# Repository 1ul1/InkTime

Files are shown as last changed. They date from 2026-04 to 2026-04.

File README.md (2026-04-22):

# InkTime
## Block Diagram

If GitHub does not render Mermaid, use this ASCII version instead:

# Block Diagram

### Summary

The nRF52840 is the main controller of the board.
Power comes from USB-C and the Li-Po battery through the BQ25180 charger and the RT6160A DC/DC regulator. The MCU talks over I2C with the BMA421 IMU, MAX17048 fuel gauge, and DRV2605 haptic driver. It also controls the E-Paper display through SPI and extra control lines, reads the buttons, and exposes SWD for programming and debug.

### Overview
```
USB-C -----> nRF52840 <-----> BMA421 IMU
  |             |               (I2C)
  |             |
  |             +-------------> Buttons
  |             |
  |             +-------------> SWD Header
  |             |
  |             +-------------> E-Paper Display
  |                    (SPI + control)
  |
  +-----> BQ25180 Charger -----> Li-Po Battery
                 |
                 +-----> RT6160A DC/DC -----> 3V3 
                                          |-> nRF52840
                                          |-> MAX17048 Fuel Gauge
                                          |-> DRV2605 Haptic Driver
                                          |-> E-Paper Drive Circuit
```

## Bill of Materials (BOM)

The table below lists the main parts used in the project.  
For standard passives (0201 / 0402 capacitors and resistors), the exact values and designators are already included in `BOM.csv`.  
JLC links below are **search links**, so you can quickly find the matching part on JLC Parts.

| Designators | Qty | Part / Function | Manufacturer | MPN | Package / Notes | JLC Parts | Datasheet |
|---|---:|---|---|---|---|---|---|
| U1 | 1 | Main MCU | Nordic Semiconductor | nRF52840 | AQFN-73 / 7x7 mm | [JLC Search](https://jlcpcb.com/parts/componentSearch?searchTxt=nRF52840) | [Datasheet](https://docs.nordicsemi.com/bundle/ps_nrf52840/page/keyfeatures_html5.html) |
| IC1 | 1 | Li-Po charger | Texas Instruments | BQ25180YBGR | DSBGA-8 | [JLC Search](https://jlcpcb.com/parts/componentSearch?searchTxt=BQ25180YBGR) | [Datasheet](https://www.ti.com/lit/gpn/BQ25180) |
| IC9 | 1 | Buck-boost regulator | Richtek | RT6160AWSC | WL-CSP-15 | [JLC Search](https://jlcpcb.com/parts/componentSearch?searchTxt=RT6160AWSC) | [Datasheet](https://www.mouser.com/datasheet/2/1458/DS6160A_02-3104604.pdf) |
| IC3 | 1 | IMU / accelerometer | Bosch Sensortec | BMA423 | LGA-12 | [JLC Search](https://jlcpcb.com/parts/componentSearch?searchTxt=BMA423) | [Datasheet](https://watchy.sqfmi.com/assets/files/BST-BMA423-DS000-1509600-950150f51058597a6234dd3eaafbb1f0.pdf) |
| U3 | 1 | Fuel gauge | Analog Devices / Maxim | MAX17048G+T10 | 9-bump UCSP | [JLC Search](https://jlcpcb.com/parts/componentSearch?searchTxt=MAX17048G%2BT10) | [Datasheet](https://www.analog.com/media/en/technical-documentation/data-sheets/max17048-max17049.pdf) |
| IC2 | 1 | Haptic driver | Texas Instruments | DRV2605YZFR | DSBGA-9 | [JLC Search](https://jlcpcb.com/parts/componentSearch?searchTxt=DRV2605YZFR) | [Datasheet](https://www.ti.com/lit/ds/symlink/drv2605.pdf) |
| ANT1 | 1 | 2.4 GHz chip antenna | Johanson Technology | 2450AT18B100E | Ceramic antenna | [JLC Search](https://jlcpcb.com/parts/componentSearch?searchTxt=2450AT18B100E) | [Datasheet](https://www.johansontechnology.com/docs/1187/2450AT18B100_X8XXogU.pdf) |
| J1 | 1 | E-paper FPC connector | Molex | 503480-2400 | 24-pin, 0.5 mm pitch | [JLC Search](https://jlcpcb.com/parts/componentSearch?searchTxt=503480-2400) | [Datasheet](https://www.molex.com/en-us/products/part-detail/5034802400) |
| J4 | 1 | USB-C connector | Kinghelm | KH-TYPE-C-16P | USB Type-C, SMT | [JLC Search](https://jlcpcb.com/parts/componentSearch?searchTxt=KH-TYPE-C-16P) | [Datasheet](https://datasheet.lcsc.com/lcsc/2404191039_Shenzhen-Kinghelm-Elec-KH-TYPE-C-16P_C709357.pdf) |
| J2 | 1 | SWD programming connector | Tag-Connect | TC2030-IDC | 6-pin cable / debug | [JLC Search](https://jlcpcb.com/parts/componentSearch?searchTxt=TC2030-IDC) | [Datasheet](https://www.tag-connect.com/wp-content/uploads/bsk-pdf-manager/2019/12/TC2030-IDC-Datasheet-Rev-B.pdf) |
| D3 | 1 | USB ESD protection | STMicroelectronics | USBLC6-2SC6Y | SOT-23-6 | [JLC Search](https://jlcpcb.com/parts/componentSearch?searchTxt=USBLC6-2SC6Y) | [Datasheet](https://www.st.com/resource/en/datasheet/usblc6-2sc6y.pdf) |
| D2, D4, D5 | 3 | Schottky diode | onsemi | MBR0530 | SOD-123 | [JLC Search](https://jlcpcb.com/parts/componentSearch?searchTxt=MBR0530) | [Datasheet](https://www.onsemi.com/pdf/datasheet/mbr0530t1-d.pdf) |
| Q3 | 1 | N-MOSFET | Vishay | SI1308EDL-T1-GE3 | SC-70 | [JLC Search](https://jlcpcb.com/parts/componentSearch?searchTxt=SI1308EDL-T1-GE3) | [Datasheet](https://www.vishay.com/docs/63399/si1308edl.pdf) |
| Q1 | 1 | P-MOSFET | Diodes Inc. / equivalent | DMG2305UX-7 | SOT-23 | [JLC Search](https://jlcpcb.com/parts/componentSearch?searchTxt=DMG2305UX-7) | [Datasheet](https://www.diodes.com/assets/Datasheets/DMG2305UX.pdf) |
| L7 | 1 | Power inductor | TDK | MLP2016SR47MT0S1 | 0.47 uH | [JLC Search](https://jlcpcb.com/parts/componentSearch?searchTxt=MLP2016SR47MT0S1) | [Datasheet](https://product.tdk.com/system/files/dam/doc/product/inductor/inductor/smd/catalog/inductor_commercial_multilayer_mlp2016_en.pdf) |
| L5 | 1 | Inductor | Generic / selected by value | 68uH | E-paper drive | [JLC Search](https://jlcpcb.com/parts/componentSearch?searchTxt=68uH) | - |
| L2 | 1 | Inductor | Generic / selected by value | 10uH | Power stage | [JLC Search](https://jlcpcb.com/parts/componentSearch?searchTxt=10uH) | - |
| L1 | 1 | RF inductor | Generic / selected by value | 3.9nH | RF matching | [JLC Search](https://jlcpcb.com/parts/componentSearch?searchTxt=3.9nH) | - |
| L3 | 1 | RF inductor | Generic / selected by value | 15nH | RF matching | [JLC Search](https://jlcpcb.com/parts/componentSearch?searchTxt=15nH) | - |
| X1 | 1 | High-frequency crystal | Generic / selected by value | 32MHz | 2016 package | [JLC Search](https://jlcpcb.com/parts/componentSearch?searchTxt=32MHz) | - |
| X2 | 1 | RTC crystal | Generic / selected by value | 32.768kHz | 3215 package | [JLC Search](https://jlcpcb.com/parts/componentSearch?searchTxt=32.768kHz) | - |
| SW_UP, SW_ENT, SW_DN | 3 | Push buttons | Panasonic | EVP-AKE31A | SMD tactile switch | [JLC Search](https://jlcpcb.com/parts/componentSearch?searchTxt=EVP-AKE31A) | [Datasheet](https://industrial.panasonic.com/cdbs/www-data/pdf/ABV0000/ABV0000C90.pdf) |
| TP_3.3V, TP_BAT_GND, TP_GND, TP_ON, TP_OP, TP_RESET, TP_SCL, TP_SDA, TP_SWDCLK, TP_SWDIO, TP_SWO, TP_VBAT | 12 | Test pads | Generic | TP20R | Debug / measurement | [JLC Search](https://jlcpcb.com/parts/componentSearch?searchTxt=test%20pad) | - |

### Standard passives

The board also uses standard SMD resistors and capacitors:

- **All resistors:** 0201
- **Capacitors <= 100 nF:** 0201
- **Capacitors > 100 nF:** 0402
- Exceptions are used only where the schematic explicitly asks for another case

Examples from this design:
- 12 pF, 1 pF, 100 nF, 47 nF, 820 pF, 100 pF capacitors
- 1 uF, 4.7 uF, 10 uF, 22 uF capacitors
- 0R, 2.2R, 470 mR, 3.3 kR, 5.1 kR, 10 kR resistors

For these passives, the exact reference designators, values, and package choices are already listed in `BOM.csv`.

## Hardware Overview

[SCHEMATIC](./Hardware/Schematic.pdf)

### MCU: nRF52840
Central processor managing all peripherals and communication interfaces (GPIO, I2C, SPI, USB).

### Power section
Li‑Po charger (BQ25180) and DC/DC regulator (RT6160A) handle battery charging and generate system voltage rails.

### IMU
BMA421 accelerometer on the I2C bus providing motion data and interrupt outputs.

### USB‑C and ESD protection
USB‑C port supplies power and data, with ESD components protecting the USB lines.

### E‑Paper display
SPI‑driven display connected via FPC, supported by dedicated driving circuitry for panel voltages.

### Fuel gauge
MAX17048 on I2C measuring battery voltage and state‑of‑charge.

### Buttons
Three user buttons (UP, ENTER, DOWN) connected to MCU GPIO pins.

### Haptic driver
DRV2605 (I2C) controlling a vibration motor for tactile feedback.

### SWD debug header
Provides SWDIO, SWDCLK, reset, power, and ground for programming and debugging.

### Block connections
Power flows from USB/battery through charger and regulators; I2C links IMU, fuel gauge, and haptics; SPI and control lines drive the display; GPIO handles buttons and interrupts.

## Central processor - nRF52840

### Short summary
The nRF52840 coordinates the entire system—power, sensors, display, buttons, and haptics—acting as the central controller for all board functions.

### Pins

the nRF52840 uses:
- **native USB pins** for USB,
- **one shared I2C bus** for low-speed peripheral chips,
- **SPI + control pins** for the e-paper display,
- **GPIO inputs** for buttons,
- **interrupt pins** for IMU, battery, and power events,
- and **SWD pins** for debug.

### Why these choices make sense

- **USB** is connected to the nRF52840 native USB pins, so firmware upload and USB communication are direct and simple.
- **I2C** is used for support chips like the charger, IMU, fuel gauge, and haptic driver because these parts only need low-speed control.
- **SPI** is used for the e-paper display because it is better for sending display data.
- **Interrupt lines** such as **ALERT**, **PMIC_INT**, **IMU_INT1**, and **IMU_INT2** help the MCU wake up only when needed, which is better for low power.
- **Buttons** are on simple GPIO pins because they only need digital input reads.
- **SWDIO**, **SWDCLK**, and **RESET** are broken out for easy programming and debugging during bring-up.

## End Result

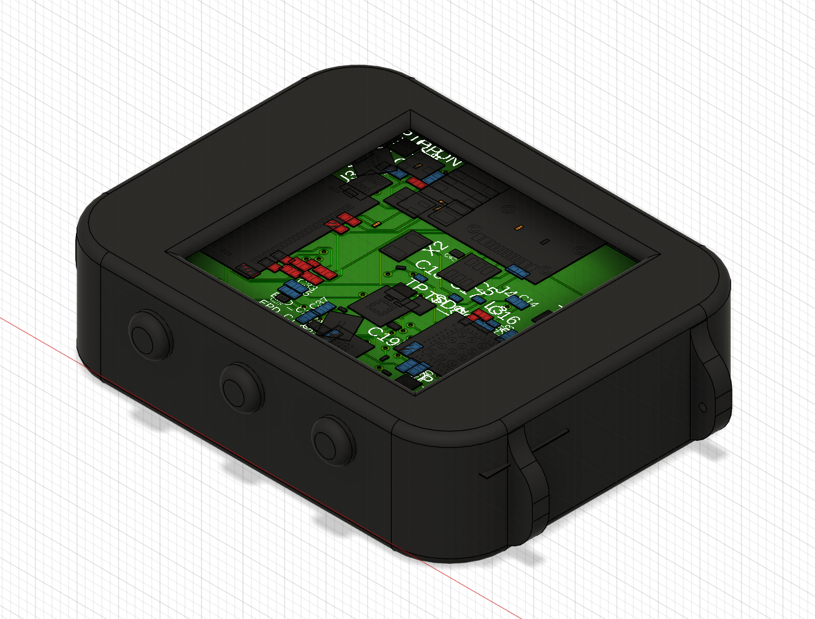
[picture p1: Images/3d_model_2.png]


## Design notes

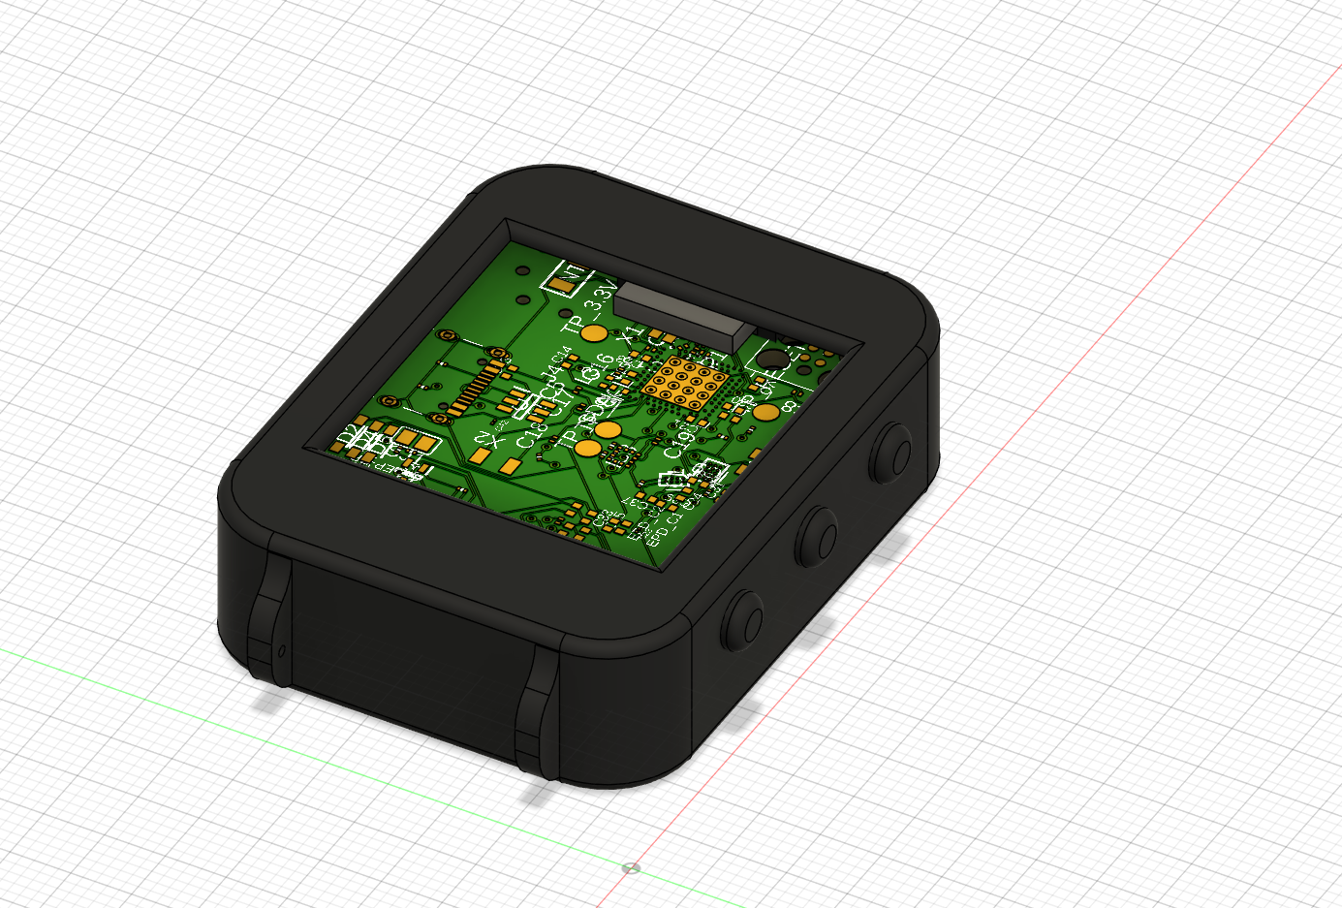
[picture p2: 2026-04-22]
Images/3d_model.png

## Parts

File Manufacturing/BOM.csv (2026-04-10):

Reference Designators | Quantity | Description | Package | Value | Manufacturer | Manufacturer Part Number | Vendor | Vendor Part Number | Top/Bottom
 | 1 | PCB Board | Board
ANT1 | 1 | Antennas 2.45GHz ANTENNA | 2450AT18B100E_ANTC3216X140N | 2450AT18B100E_2450AT18B100E |  |  |  |  | Top
C1, C2, C17, C18 | 4 | Generic chip capacitor | NORDIC_NRF_3_RESC0201_L | 12pF |  |  |  |  | Top
C1-EP-DR, C24, C39 | 3 | 0402 (1005 Metric) | PERFECT_0402_0402 | 10uF |  |  |  |  | Top
C2-EP-DR | 1 | 0402 (1005 Metric) | PERFECT_0402_0402 | 4.7uF/25V |  |  |  |  | Top
C3, C4 | 2 | Generic chip capacitor | NORDIC_NRF_3_RESC0201_L | 1pF |  |  |  |  | Top
C5, C8, C12, C19 | 4 | Generic chip capacitor | NORDIC_NRF_3_RESC0201_L | 100nF |  |  |  |  | Top
C6, C14, C20, C21 | 4 | 0402 (1005 Metric) | PERFECT_0402_0402 | 4.7µF |  |  |  |  | Top
C7 | 1 | 0402 (1005 Metric) | PERFECT_0402_0402 | 100nF |  |  |  |  | Top
C9 | 1 | Generic chip capacitor | NORDIC_NRF_3_RESC0201_L | 820pF |  |  |  |  | Top
C10 | 1 | Generic chip capacitor | NORDIC_NRF_3_RESC0201_L | N.C. |  |  |  |  | Top
C11 | 1 | Generic chip capacitor | NORDIC_NRF_3_RESC0201_L | 100pF |  |  |  |  | Top
C13 | 1 | 0402 (1005 Metric) | PERFECT_0402_0402 | N.C. |  |  |  |  | Top
C15 | 1 | 0402 (1005 Metric) | PERFECT_0402_0402 | 1.0µF |  |  |  |  | Top
C16 | 1 | Generic chip capacitor | NORDIC_NRF_3_RESC0201_L | 47nF |  |  |  |  | Top
C22 | 1 | Generic chip capacitor | NORDIC_NRF_3_RESC0201_L | N.C |  |  |  |  | Top
C23, C27, C34, C42 | 4 | Check availability | CAPC0201X13N | 0.1uF |  |  |  |  | Top
C25, C33 | 2 | 0402 (1005 Metric) | PERFECT_0402_0402 | 22uF |  |  |  |  | Top
C29, C30, C31, C32, C37, C38 | 6 | 0402 (1005 Metric) | PERFECT_0402_0402 | 1uF |  |  |  |  | Top
C43 | 1 | 0402 (1005 Metric) | PERFECT_0402_0402 | 4.7uF |  |  |  |  | Top
D2, D4, D5 | 3 | ON SEMICONDUCTOR - MBR0530 - DIODE, SCHOTTKY, 0.5A, 30V, SOD-123 | SOD3716X135N | ESP32_C6_LIBRARY_5_MBR0530 |  |  |  |  | Top
D3 | 1 | Low Cap. ESD Protection Auto SOT-23-6 STMicroelectronics USBLC6-2SC6Y, Dual Uni-Directional TVS Diode Array, 6-Pin SOT-23 | SOT95P280X145-6N | ESP32_C6_LIBRARY_3_USBLC6-2SC6Y |  |  |  |  | Top
EPD_C1, EPD_C2, EPD_C6, EPD_C7, EPD_C8, EPD_C9, EPD_C10, EPD_C11, EPD_C12 | 9 | 0402 (1005 Metric) | PERFECT_0402_0402 | 1uF/50V |  |  |  |  | Top
EPD_C5 | 1 | Generic chip capacitor | NORDIC_NRF_3_RESC0201_L | 0.1uF/50V |  |  |  |  | Top
IC1 | 1 | Charger IC Lithium Ion/Polymer, Lithium Iron Phosphate 8-DSBGA (1.6x1.1) | BQ25180YBGR_BGA8C40P2X4_100X155X50 | BQ25180YBGR_BQ25180YBGR |  |  |  |  | Top
IC2 | 1 | Haptic Driver for ERM/LRA with Built-In Library and Smart Loop Architecture | DRV2605YZFR_BGA9C50P3X3_144X144X62 | DRV2605YZFR_DRV2605YZFR |  |  |  |  | Top
IC3 | 1 | Accelerometers Triaxial low-g 12bit Acceleration Sensor | BMA423_BMA423 | BMA423_BMA423 |  |  |  |  | Top
IC9 | 1 | Buck-Boost Regulator Positive Output Step-Up/Step-Down I2C DC-DC Controller IC 15-WL-CSP (BSC) (1.4x2.3) | RT6160AWSC_BGA15C40P3X5_140X230X60 | RT6160AWSC_RT6160AWSC |  |  |  |  | Top
J1 | 1 | FFC & FPC Connectors 0.5mm FPC RA SMT Dual Contact 24Ckt | 503480-2400_5034802400 | 503480-2400_503480-2400 |  |  |  |  | Top
J2 | 1 | CABLE ADAPTER 6 POS | TC2030-IDC_TC2030IDC | TC2030-IDC_TC2030-IDC |  |  |  |  | Top
J4 | 1 | Check availability | KINGHELM_KH-TYPE-C-16P | KH-TYPE-C-16P_KH-TYPE-C-16P |  |  |  |  | Top
L1 | 1 | Generic chip inductor | NORDIC_NRF_2_RESC0402_L | 3.9nH |  |  |  |  | Top
L2 | 1 | Generic chip inductor | NORDIC_NRF_2_RESC0402_L | 10µH |  |  |  |  | Top
L3 | 1 | Generic chip inductor | NORDIC_NRF_2_RESC0402_L | 15nH |  |  |  |  | Top
L5 | 1 | Generic chip inductor | NORDIC_NRF_2_RESC0402_L | 68uH |  |  |  |  | Top
L7 | 1 | SMD / SMT Inductors (Coils), L=0.47?H, L x W x T : | MLP2016SR47MT0S1_INDC2016X100N | MLP2016SR47MT0S1_FTC252012SR47MBCA |  |  |  |  | Top
Q1 | 1 | P-channel MOSFETs | ESP32_WROVER_SPARKFUN-DISCRETESEMI_SOT23-3 | 20V/4.2A/52mΩ/1.4W |  |  |  |  | Top
Q3 | 1 | MOSFET N-Ch 30V 1.5A TrenchFET SC70 Vishay Si1308EDL-T1-GE3 N-channel MOSFET Transistor, 1.5 A, 30 V, 3-Pin SC-70 | SOT65P210X110-3N | ESP32_C6_LIBRARY_6_SI1308EDL-T1-GE3 |  |  |  |  | Top
R_PWR_EPD, R2_EP_DR, R9 | 3 | 7.68k 0201 Thin Film Surface Mount Fixed Resistor +/-0.5% 0.031W CPF0201D7K68C1 | CPF0201D7K68C1_0201 | 10K |  |  |  |  | Top
R_TYPE_SEL | 1 | 7.68k 0201 Thin Film Surface Mount Fixed Resistor +/-0.5% 0.031W CPF0201D7K68C1 | CPF0201D7K68C1_0201 | 2.2 |  |  |  |  | Top
R1_EP_DR | 1 | 7.68k 0201 Thin Film Surface Mount Fixed Resistor +/-0.5% 0.031W CPF0201D7K68C1 | CPF0201D7K68C1_0201 | 0.47 |  |  |  |  | Top
R1_USB, R2_USB | 2 | 7.68k 0201 Thin Film Surface Mount Fixed Resistor +/-0.5% 0.031W CPF0201D7K68C1 | CPF0201D7K68C1_0201 | 5K1 |  |  |  |  | Top
R2, R3, R4 | 3 | 7.68k 0201 Thin Film Surface Mount Fixed Resistor +/-0.5% 0.031W CPF0201D7K68C1 | R0201 | 0 |  |  |  |  | Top
R5, R7, R8 | 3 | 7.68k 0201 Thin Film Surface Mount Fixed Resistor +/-0.5% 0.031W CPF0201D7K68C1 | CPF0201D7K68C1_0201 | 10k |  |  |  |  | Top
R17, R18 | 2 | 7.68k 0201 Thin Film Surface Mount Fixed Resistor +/-0.5% 0.031W CPF0201D7K68C1 | R0201 | 3K3 |  |  |  |  | Top
SJ1 | 1 | SMD solder JUMPER | JUMPER_SJ | 0 |  |  |  |  | Top
SW_DN, SW_ENT, SW_UP | 3 |  | SW_EVP-AKE31A_PAN | 2025-10-22_07-23-44_LIBRARY_EVP-AKE31ASW_EVP-AKE31A_PAN |  |  |  |  | Top
TP_3.3V, TP_BAT_GND, TP_GND, TP_ON, TP_OP, TP_RESET, TP_SCL, TP_SDA, TP_SWDCLK, TP_SWDIO, TP_SWO, TP_VBAT | 12 | Test pad | HECTOR_WATCH_1_TP20R | HECTOR_WATCH_1_TPTP20R |  |  |  |  | Top
U1 | 1 | nRF52840 | NORDIC_NRF_4_AQFN50P700X700X85_HS-74N | NORDIC_NRF_4_NRF52840_QF |  |  |  |  | Top
U3 | 1 | Check availability | SON50P200X200X80-9N | ESP32_C6_LIBRARY_MAX17048G+T10 |  |  |  |  | Top
X1 | 1 |  | NORDIC_NRF_BT-XTAL_2016_N | 32MHZ |  |  |  |  | Top
X2 | 1 |  | NORDIC_NRF_1_XTAL_3215_N | 32.768kHz |  |  |  |  | Top

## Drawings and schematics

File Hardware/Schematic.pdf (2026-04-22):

# LIPo Charger

# DC/DC

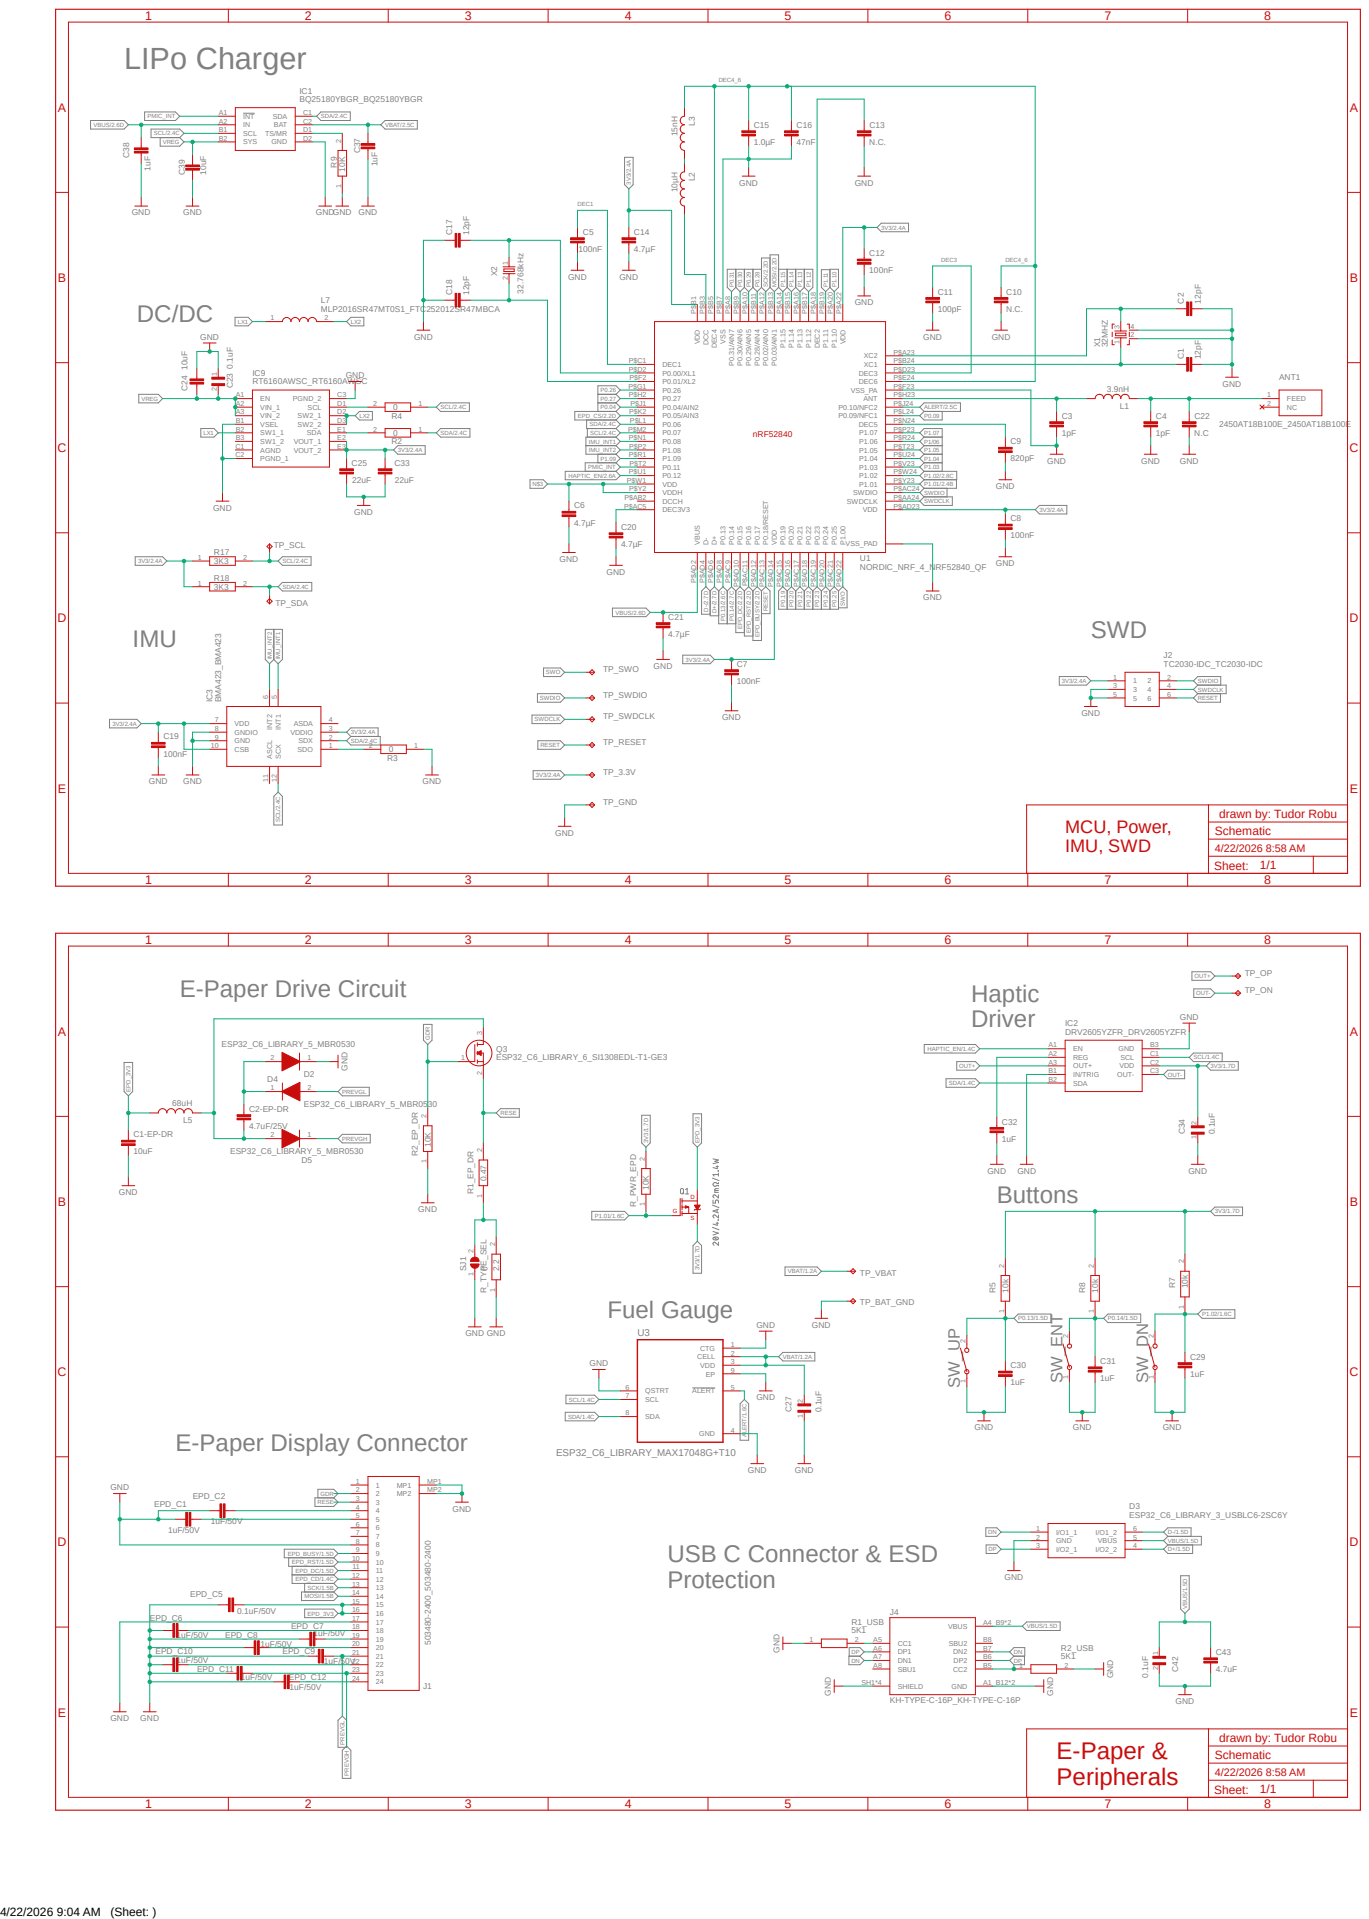
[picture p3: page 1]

1uF/50V EPD_C8 | 1uF/50V | 19 19

EPD_C11 | | 23 23

1uF/50V | EPD_C12 | 24 24

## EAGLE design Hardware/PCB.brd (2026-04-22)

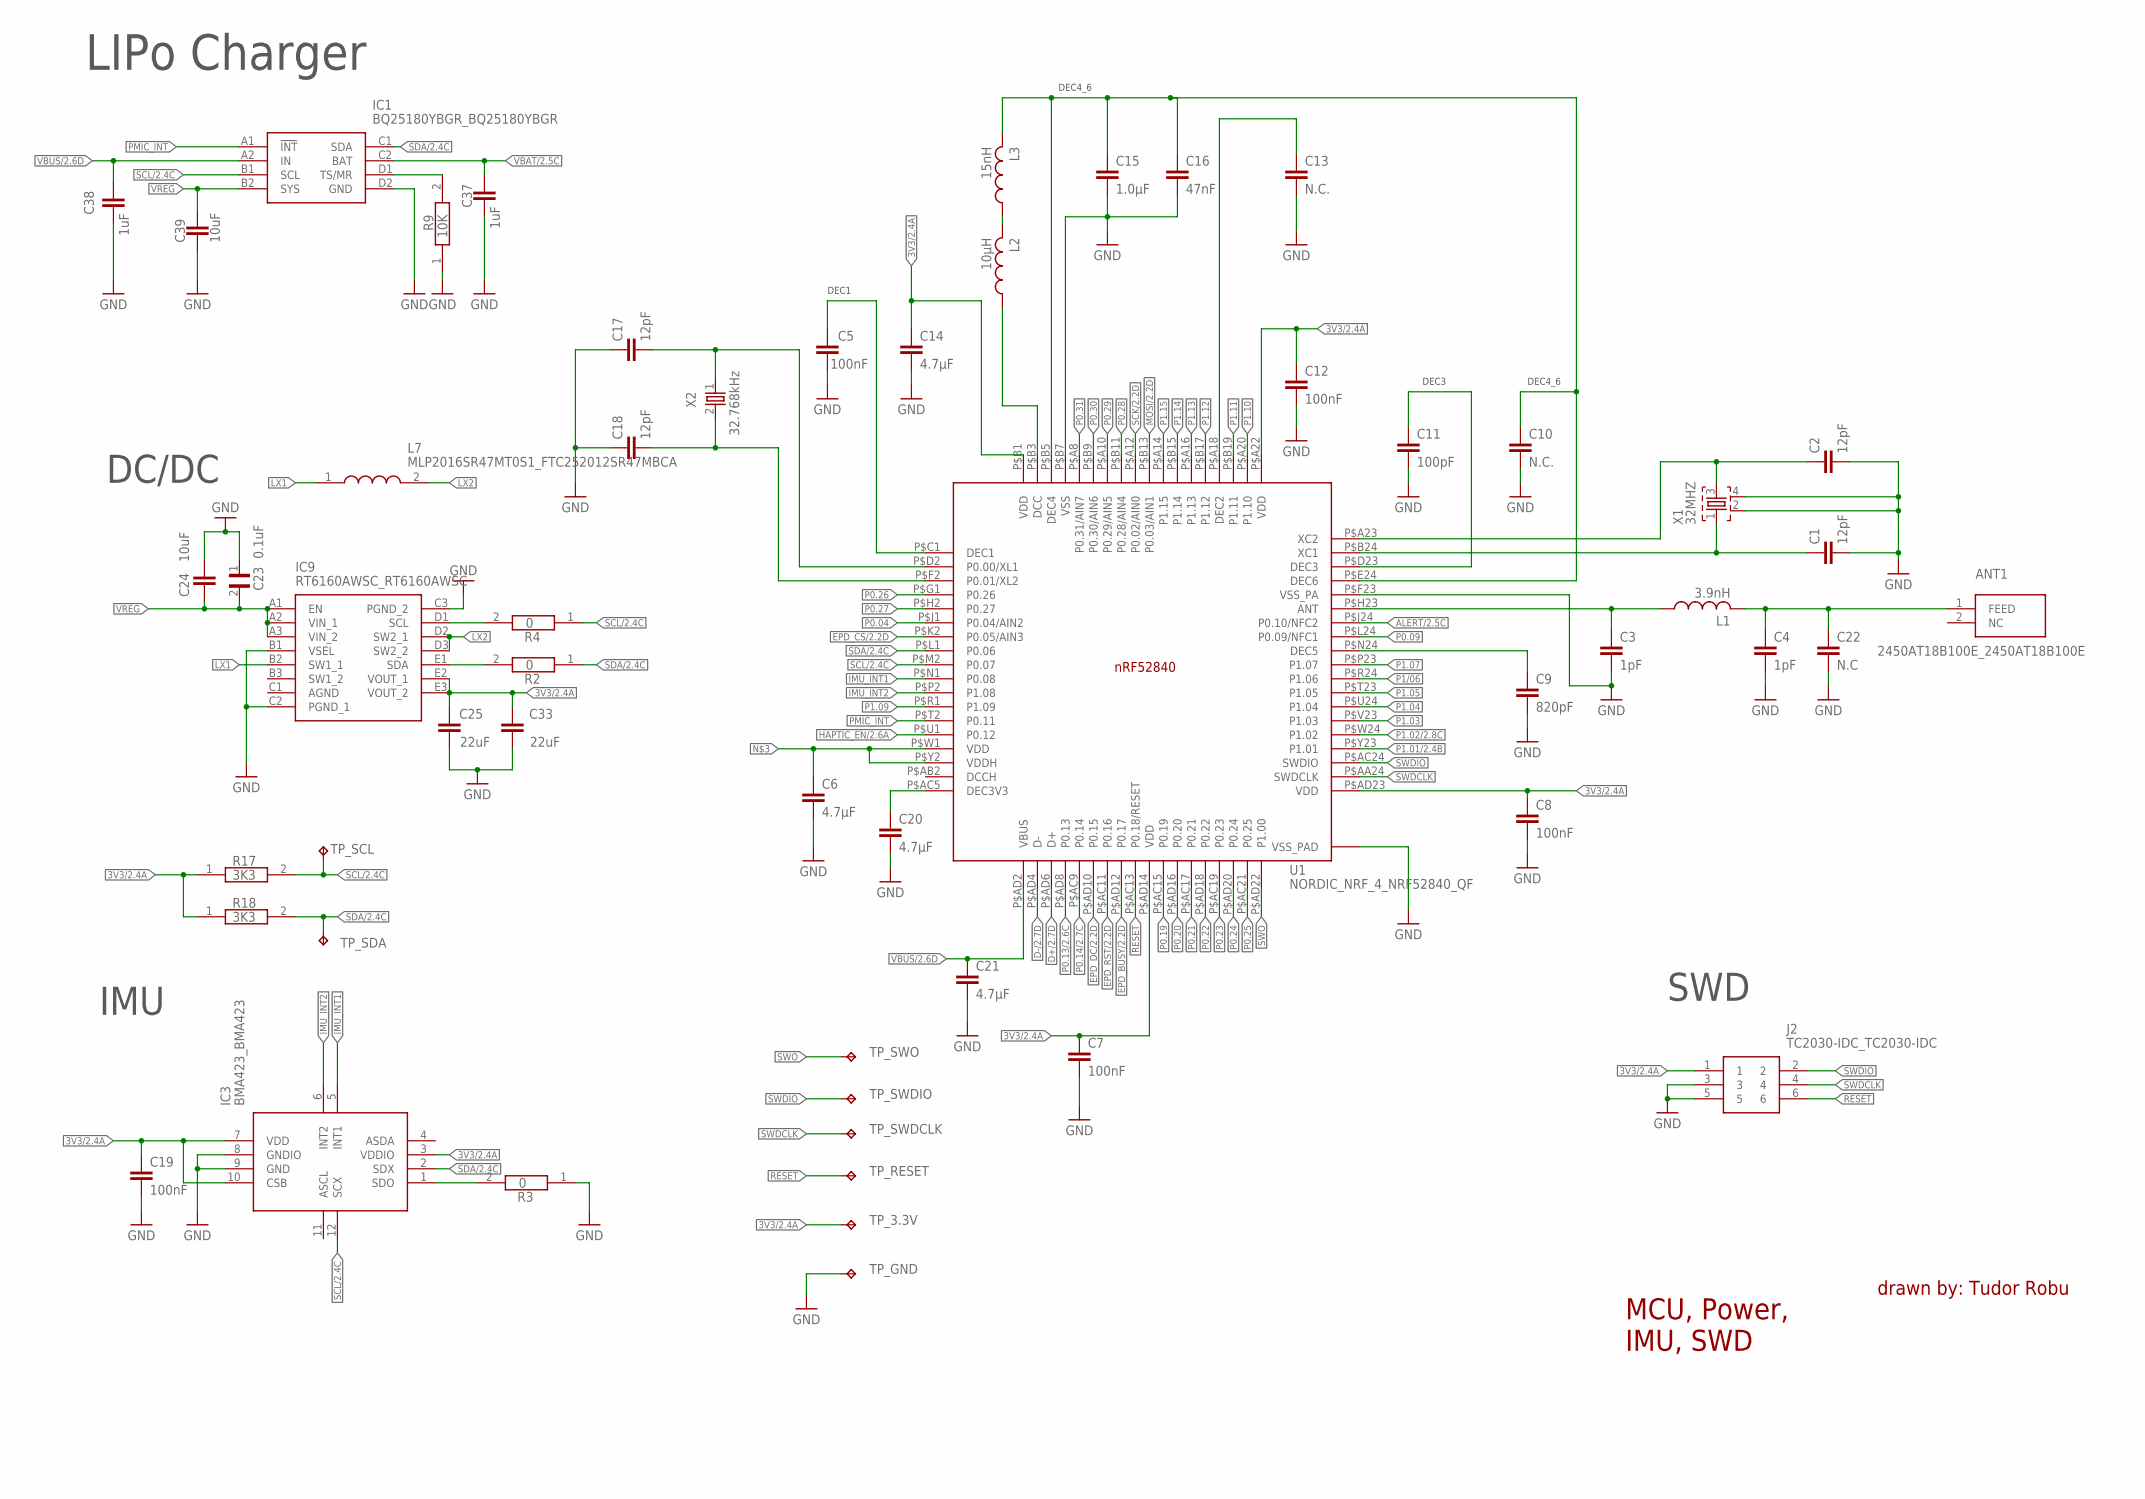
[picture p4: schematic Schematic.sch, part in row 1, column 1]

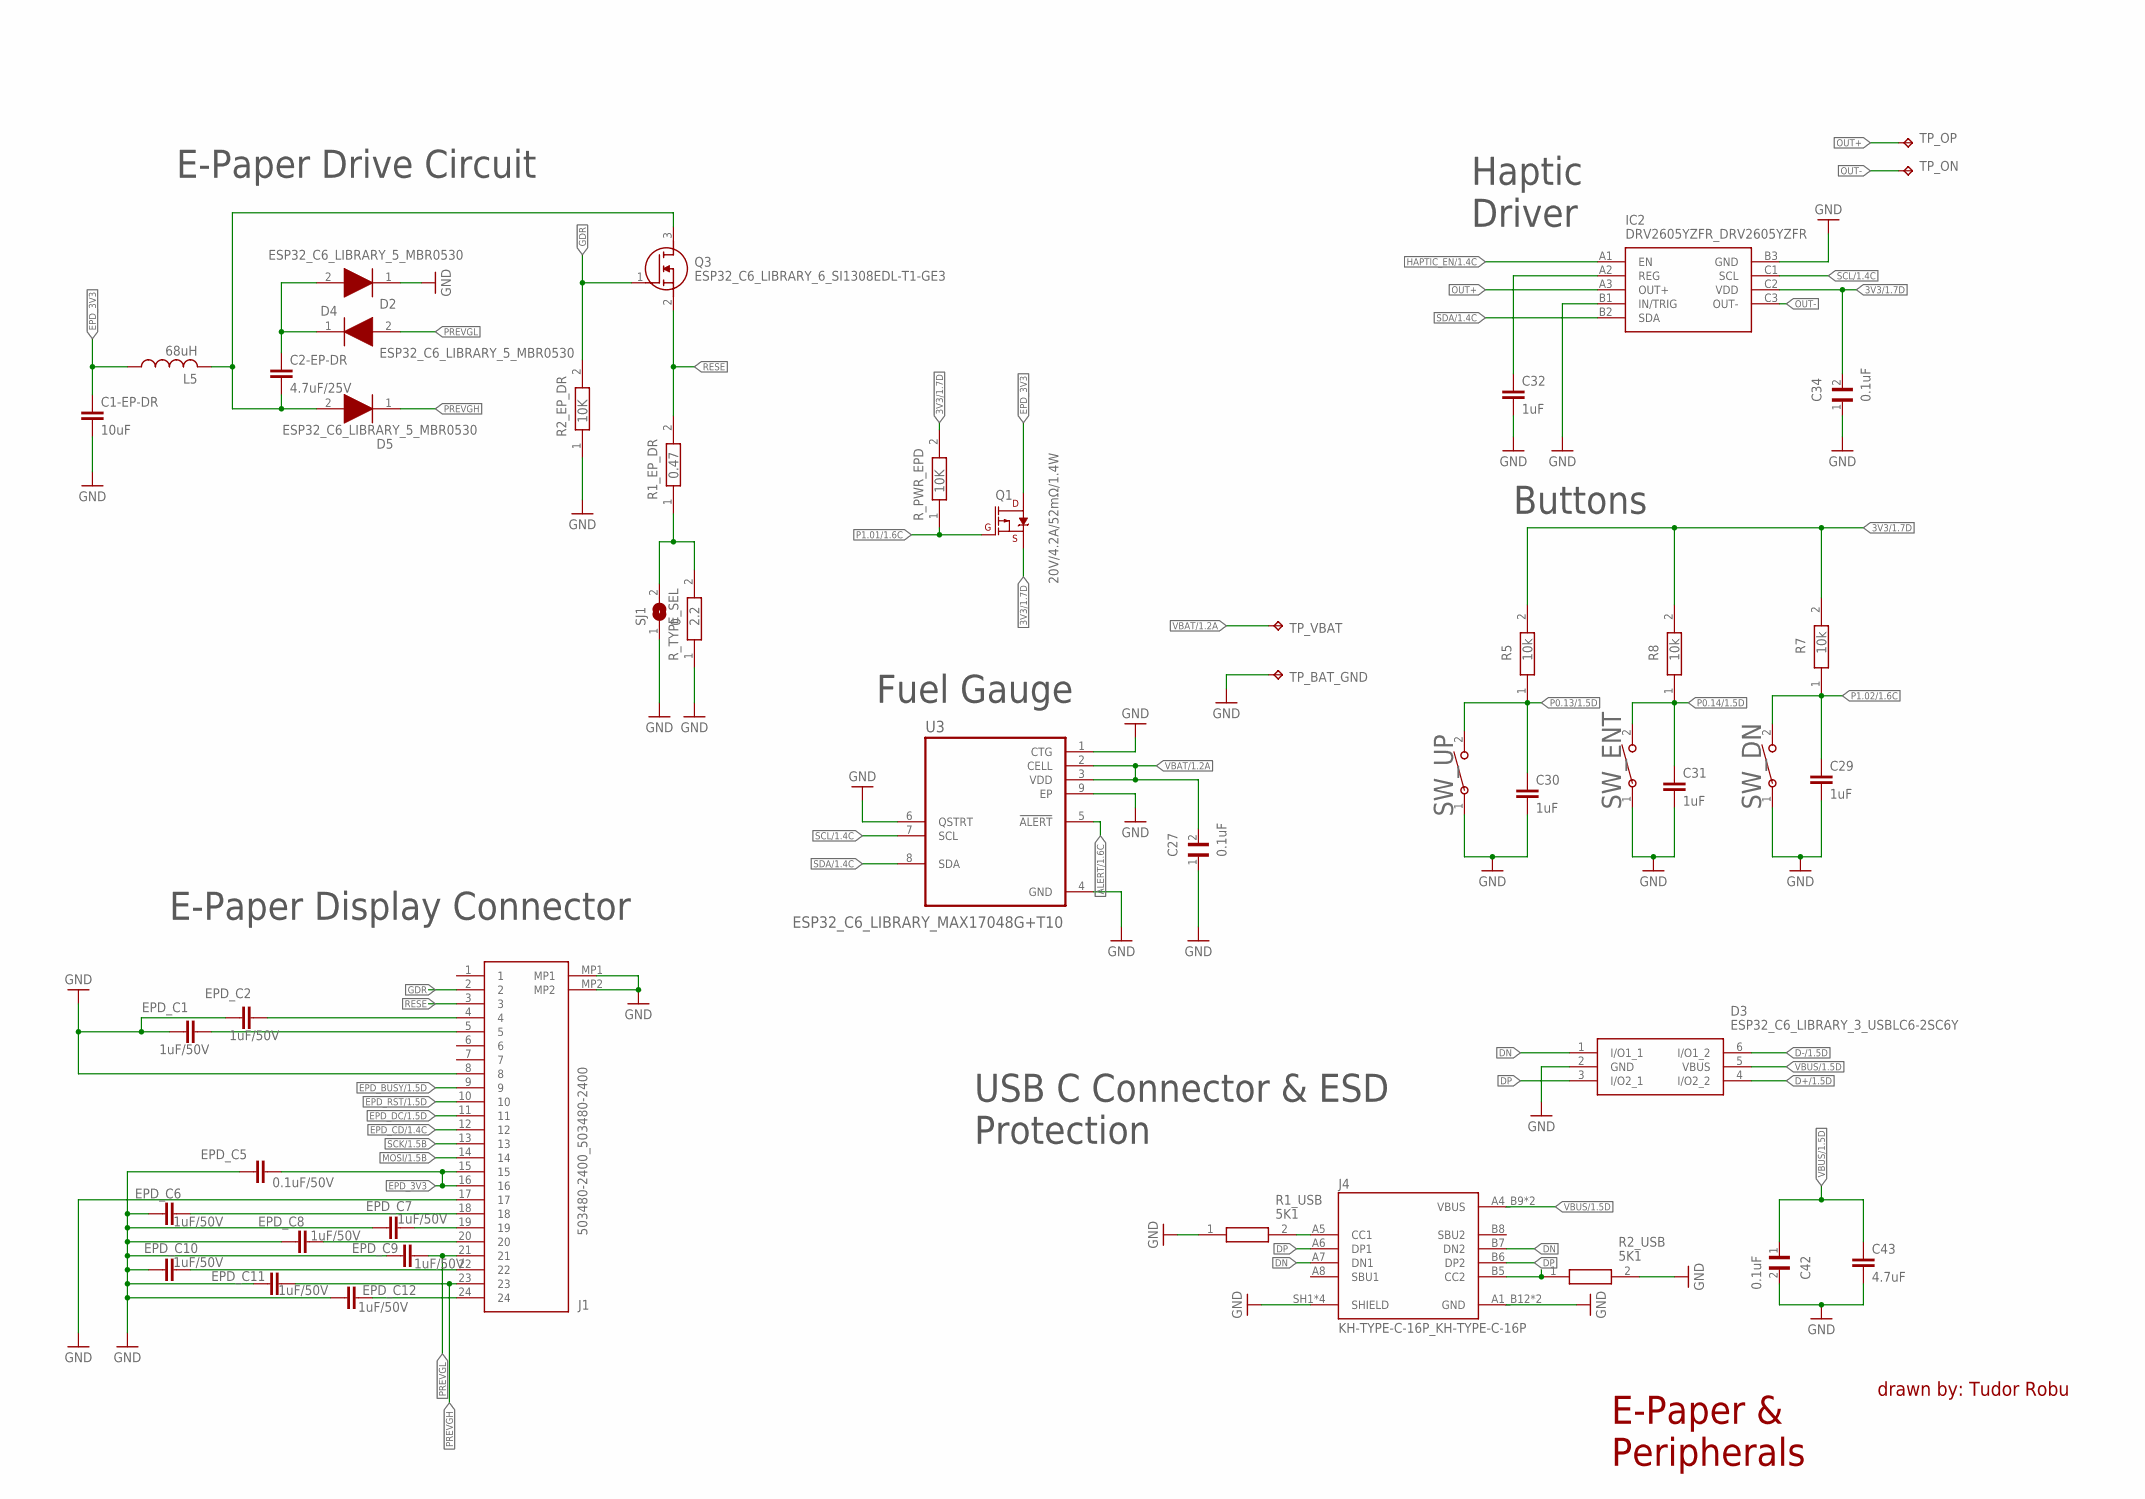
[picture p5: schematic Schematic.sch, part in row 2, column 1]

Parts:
ANT1: 2450AT18B100E_2450AT18B100E; 2450AT18B100E_ANTC3216X140N
C1, C2, C17, C18: 12pF; NORDIC_NRF_3_RESC0201_L
C1-EP-DR, C24, C39: 10uF; PERFECT_0402_0402
C2-EP-DR: 4.7uF/25V; PERFECT_0402_0402
C3, C4: 1pF; NORDIC_NRF_3_RESC0201_L
C5, C8, C12, C19: 100nF; NORDIC_NRF_3_RESC0201_L
C6, C14, C20, C21: 4.7µF; PERFECT_0402_0402
C7: 100nF; PERFECT_0402_0402
C9: 820pF; NORDIC_NRF_3_RESC0201_L
C10: N.C.; NORDIC_NRF_3_RESC0201_L
C11: 100pF; NORDIC_NRF_3_RESC0201_L
C13: N.C.; PERFECT_0402_0402
C15: 1.0µF; PERFECT_0402_0402
C16: 47nF; NORDIC_NRF_3_RESC0201_L
C22: N.C; NORDIC_NRF_3_RESC0201_L
C23, C27, C34, C42: 0.1uF; GRM011R60J152KE01L_2_CAPC0201X13N
C25, C33: 22uF; PERFECT_0402_0402
C29, C30, C31, C32, C37, C38: 1uF; PERFECT_0402_0402
C43: 4.7uF; PERFECT_0402_0402
D2, D4, D5: ESP32_C6_LIBRARY_5_MBR0530; ESP32_C6_LIBRARY_5_SOD3716X135N
D3: ESP32_C6_LIBRARY_3_USBLC6-2SC6Y; ESP32_C6_LIBRARY_3_SOT95P280X145-6N
EPD_C1, EPD_C2, EPD_C6, EPD_C7, EPD_C8, EPD_C9, EPD_C10, EPD_C11, EPD_C12: 1uF/50V; PERFECT_0402_0402
EPD_C5: 0.1uF/50V; NORDIC_NRF_3_RESC0201_L
IC1: BQ25180YBGR_BQ25180YBGR; BQ25180YBGR_BGA8C40P2X4_100X155X50
IC2: DRV2605YZFR_DRV2605YZFR; DRV2605YZFR_BGA9C50P3X3_144X144X62
IC3: BMA423_BMA423
IC9: RT6160AWSC_RT6160AWSC; RT6160AWSC_BGA15C40P3X5_140X230X60
J1: 503480-2400_503480-2400; 503480-2400_5034802400
J2: TC2030-IDC_TC2030-IDC; TC2030-IDC_TC2030IDC
J4: KH-TYPE-C-16P_KH-TYPE-C-16P; KH-TYPE-C-16P_KINGHELM_KH-TYPE-C-16P
L1: 3.9nH; NORDIC_NRF_2_RESC0402_L
L2: 10µH; NORDIC_NRF_2_RESC0402_L
L3: 15nH; NORDIC_NRF_2_RESC0402_L
L5: 68uH; NORDIC_NRF_2_RESC0402_L
L7: MLP2016SR47MT0S1_FTC252012SR47MBCA; MLP2016SR47MT0S1_INDC2016X100N
Q1: 20V/4.2A/52mΩ/1.4W; ESP32_C6_LIBRARY_4_ESP32_C6_LIBRARY_4_ESP32_C6_LIBRARY_4_ES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
Q3: ESP32_C6_LIBRARY_6_SI1308EDL-T1-GE3; ESP32_C6_LIBRARY_6_SOT65P210X110-3N
R1_EP_DR: 0.47; CPF0201D7K68C1_0201
R1_USB, R2_USB: 5K1; CPF0201D7K68C1_0201
R2, R3, R4: 0; ERA-1AEB3401C_0201
R2_EP_DR, R9: 10K; CPF0201D7K68C1_0201
R5, R7, R8: 10k; CPF0201D7K68C1_0201
R17, R18: 3K3; ERA-1AEB3401C_0201
R_PWR_EPD: 10K; CPF0201D7K68C1_0201
R_TYPE_SEL: 2.2; CPF0201D7K68C1_0201
SJ1: 0; ESP32_C6_LIBRARY_7_JUMPER_SJ
SW_DN: 2025-10-22_07-23-44_LIBRARY_EVP-AKE31ASW_EVP-AKE3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; 2025-10-22_07-23-44_LIBRARY_SW_EVP-AKE31A_PAN
SW_ENT: 2025-10-22_07-23-44_LIBRARY_EVP-AKE31ASW_EVP-AKE3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; 2025-10-22_07-23-44_LIBRARY_SW_EVP-AKE31A_PAN
SW_UP: 2025-10-22_07-23-44_LIBRARY_EVP-AKE31ASW_EVP-AKE3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; 2025-10-22_07-23-44_LIBRARY_SW_EVP-AKE31A_PAN
TP_3.3V: HECTOR_WATCH_1_TPTP20R; HECTOR_WATCH_1_TP20R
TP_BAT_GND: HECTOR_WATCH_1_TPTP20R; HECTOR_WATCH_1_TP20R
TP_GND: HECTOR_WATCH_1_TPTP20R; HECTOR_WATCH_1_TP20R
TP_ON: HECTOR_WATCH_1_TPTP20R; HECTOR_WATCH_1_TP20R
TP_OP: HECTOR_WATCH_1_TPTP20R; HECTOR_WATCH_1_TP20R
TP_RESET: HECTOR_WATCH_1_TPTP20R; HECTOR_WATCH_1_TP20R
TP_SCL: HECTOR_WATCH_1_TPTP20R; HECTOR_WATCH_1_TP20R
TP_SDA: HECTOR_WATCH_1_TPTP20R; HECTOR_WATCH_1_TP20R
TP_SWDCLK: HECTOR_WATCH_1_TPTP20R; HECTOR_WATCH_1_TP20R
TP_SWDIO: HECTOR_WATCH_1_TPTP20R; HECTOR_WATCH_1_TP20R
TP_SWO: HECTOR_WATCH_1_TPTP20R; HECTOR_WATCH_1_TP20R
TP_VBAT: HECTOR_WATCH_1_TPTP20R; HECTOR_WATCH_1_TP20R
U1: NORDIC_NRF_4_NRF52840_QF; NORDIC_NRF_4_AQFN50P700X700X85_HS-74N
U3: ESP32_C6_LIBRARY_MAX17048G+T10; ESP32_C6_LIBRARY_SON50P200X200X80-9N
X1: 32MHZ; NORDIC_NRF_BT-XTAL_2016_N
X2: 32.768kHz; NORDIC_NRF_1_XTAL_3215_N

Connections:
3V3/1.7D: C34.2, IC2.C2 (VDD), Q1.2 (S), R5.2, R7.2, R8.2, R_PWR_EPD.2
3V3/2.4A: C7.1, C8.1, C12.1, C14.1, C19.1, C25.2, C33.2, IC3.3 (VDDIO), IC3.7 (VDD), IC3.10 (CSB), IC9.E2 (VOUT_1), IC9.E3 (VOUT_2), J2.1, R17.1, R18.1, TP_3.3V.TP, U1.P$A22 (VDD), U1.P$AD14 (VDD), U1.P$AD23 (VDD), U1.P$B1 (VDD)
ALERT/1.6C: U3.5 (!ALERT)
ALERT/2.5C: U1.P$J24 (P0.10/NFC2)
D+/1.5D: D3.4 (I/O2_2)
D+/2.7D: U1.P$AD6 (D+)
D-/1.5D: D3.6 (I/O1_2)
D-/2.7D: U1.P$AD4 (D-)
DN: D3.1 (I/O1_1), J4.A7 (DN1), J4.B7 (DN2)
DP: D3.3 (I/O2_1), J4.A6 (DP1), J4.B6 (DP2)
EPD_3V3: C1-EP-DR.1, EPD_C5.2, J1.15, J1.16, L5.1, Q1.3 (D)
EPD_BUSY/1.5D: J1.9
EPD_BUSY/2.2D: U1.P$AC11 (P0.16)
EPD_CD/1.4C: J1.12
EPD_CS/2.2D: U1.P$K2 (P0.05/AIN3)
EPD_DC/1.5D: J1.11
EPD_DC/2.2D: U1.P$AD10 (P0.15)
EPD_RST/1.5D: J1.10
EPD_RST/2.2D: U1.P$AD12 (P0.17)
GDR: J1.2, Q3.1 (G), R2_EP_DR.2
GND: C1.2, C1-EP-DR.2, C2.2, C3.2, C4.2, C5.1, C6.2, C7.2, C8.2, C9.2, C10.2, C11.2, C12.2, C13.2, C14.2, C15.2, C16.2, C17.1, C18.1, C19.2, C20.2, C21.2, C22.2, C23.1, C24.2, C25.1, C27.1, C29.2, C30.2, C31.2, C32.2, C33.1, C34.1, C37.2, C38.2, C39.2, C42.2, C43.2, D3.2 (GND), D4.1 (K), EPD_C1.1, EPD_C2.1, EPD_C5.1, EPD_C6.1, EPD_C7.1, EPD_C8.1, EPD_C9.1, EPD_C10.1, EPD_C11.1, EPD_C12.1, IC1.D2 (GND), IC2.B1 (IN/TRIG), IC2.B3 (GND), IC3.8 (GNDIO), IC3.9 (GND), IC9.B1 (VSEL), IC9.C2 (PGND_1), IC9.C3 (PGND_2), J1.8, J1.17, J1.MP1, J1.MP2, J2.3, J2.5, J4.A1_B12 (GND), J4.A12_B1 (GND), J4.SH1 (SHIELD), J4.SH2 (SHIELD), J4.SH3 (SHIELD), J4.SH4 (SHIELD), R1_USB.1, R2_EP_DR.1, R2_USB.2, R3.1, R9.1, R_TYPE_SEL.1, SJ1.1, SW_DN.1, SW_ENT.1, SW_UP.1, TP_BAT_GND.TP, TP_GND.TP, U1.P$74 (VSS_PAD), U1.P$75 (VSS_PAD), U1.P$76 (VSS_PAD), U1.P$77 (VSS_PAD), U1.P$78 (VSS_PAD), U1.P$79 (VSS_PAD), U1.P$80 (VSS_PAD), U1.P$81 (VSS_PAD), U1.P$82 (VSS_PAD), U1.P$83 (VSS_PAD), U1.P$84 (VSS_PAD), U1.P$85 (VSS_PAD), U1.P$86 (VSS_PAD), U1.P$87 (VSS_PAD), U1.P$88 (VSS_PAD), U1.P$89 (VSS_PAD), U1.P$90 (VSS_PAD), U1.P$B7 (VSS), U1.P$F23 (VSS_PA), U3.1 (CTG), U3.4 (GND), U3.6 (QSTRT), U3.9 (EP), X1.2, X1.4
HAPTIC_EN/1.4C: IC2.A1 (EN)
HAPTIC_EN/2.6A: U1.P$U1 (P0.12)
IMU_INT1: IC3.5 (INT1), U1.P$N1 (P0.08)
IMU_INT2: IC3.6 (INT2), U1.P$P2 (P1.08)
LX1: IC9.B2 (SW1_1), L7.1
LX2: IC9.D2 (SW2_1), IC9.D3 (SW2_2), L7.2
MOSI/1.5B: J1.14
MOSI/2.2D: U1.P$B13 (P0.03/AIN1)
unnamed: IC3.1 (SDO), R3.2
unnamed: C20.1, U1.P$AC5 (DEC3V3)
unnamed: C6.1, U1.P$W1 (VDD), U1.P$Y2 (VDDH)
unnamed: C18.2, U1.P$F2 (P0.01/XL2), X2.2
unnamed: C17.2, U1.P$D2 (P0.00/XL1), X2.1
unnamed: C5.2, U1.P$C1 (DEC1)
unnamed: L2.2, L3.1
unnamed: IC1.D1 (TS/MR), R9.2
unnamed: IC9.D1 (SCL), R4.2
unnamed: IC9.E1 (SDA), R2.2
unnamed: L2.1, U1.P$B3 (DCC)
unnamed: C3.1, L1.1, U1.P$H23 (ANT)
unnamed: C13.1, U1.P$A18 (DEC2)
unnamed: C10.1, C15.1, C16.1, L3.2, U1.P$B5 (DEC4), U1.P$E24 (DEC6)
unnamed: C9.1, U1.P$N24 (DEC5)
unnamed: C1.1, U1.P$B24 (XC1), X1.1
unnamed: C11.1, U1.P$D23 (DEC3)
unnamed: C2.1, U1.P$A23 (XC2), X1.3
unnamed: ANT1.1 (FEED), C4.1, C22.1, L1.2
unnamed: J4.A5 (CC1), R1_USB.2
unnamed: C2-EP-DR.2, D5.2 (A), L5.2, Q3.3 (D)
unnamed: C2-EP-DR.1, D2.1 (K), D4.2 (A)
unnamed: C32.1, IC2.A2 (REG)
unnamed: R1_EP_DR.1, R_TYPE_SEL.2, SJ1.2
unnamed: EPD_C2.2, J1.4
unnamed: EPD_C1.2, J1.5
unnamed: J4.B5 (CC2), R2_USB.1
unnamed: EPD_C12.2, J1.24
unnamed: EPD_C10.2, J1.22
unnamed: EPD_C8.2, J1.20
unnamed: EPD_C7.2, J1.19
unnamed: EPD_C6.2, J1.18
OUT+: IC2.A3 (OUT+), TP_OP.TP
OUT-: IC2.C3 (OUT-), TP_ON.TP
P0.04: U1.P$J1 (P0.04/AIN2)
P0.09: U1.P$L24 (P0.09/NFC1)
P0.13/1.5D: C30.1, R5.1, SW_UP.2
P0.13/2.6C: U1.P$AD8 (P0.13)
P0.14/1.5D: C31.1, R8.1, SW_ENT.2
P0.14/2.7C: U1.P$AC9 (P0.14)
P0.19: U1.P$AC15 (P0.19)
P0.20: U1.P$AD16 (P0.20)
P0.21: U1.P$AC17 (P0.21)
P0.22: U1.P$AD18 (P0.22)
P0.23: U1.P$AC19 (P0.23)
P0.24: U1.P$AD20 (P0.24)
P0.25: U1.P$AC21 (P0.25)
P0.26: U1.P$G1 (P0.26)
P0.27: U1.P$H2 (P0.27)
P0.28: U1.P$B11 (P0.28/AIN4)
P0.29: U1.P$A10 (P0.29/AIN5)
P0.30: U1.P$B9 (P0.30/AIN6)
P0.31: U1.P$A8 (P0.31/AIN7)
P1.01/1.6C: Q1.1 (G), R_PWR_EPD.1
P1.01/2.4B: U1.P$Y23 (P1.01)
P1.02/1.6C: C29.1, R7.1, SW_DN.2
P1.02/2.8C: U1.P$W24 (P1.02)
P1.03: U1.P$V23 (P1.03)
P1.04: U1.P$U24 (P1.04)
P1.05: U1.P$T23 (P1.05)
P1.07: U1.P$P23 (P1.07)
P1.09: U1.P$R1 (P1.09)
P1.10: U1.P$A20 (P1.10)
P1.11: U1.P$B19 (P1.11)
P1.12: U1.P$B17 (P1.12)
P1.13: U1.P$A16 (P1.13)
P1.14: U1.P$B15 (P1.14)
P1.15: U1.P$A14 (P1.15)
P1/06: U1.P$R24 (P1.06)
PMIC_INT: IC1.A1 (!INT), U1.P$T2 (P0.11)
PREVGH: D5.1 (K), EPD_C11.2, J1.23
PREVGL: D2.2 (A), EPD_C9.2, J1.21
RESE: J1.3, Q3.2 (S), R1_EP_DR.2
RESET: J2.6, TP_RESET.TP, U1.P$AC13 (P0.18/RESET)
SCK/1.5B: J1.13
SCK/2.2D: U1.P$A12 (P0.02/AIN0)
SCL/1.4C: IC2.C1 (SCL), U3.7 (SCL)
SCL/2.4C: IC1.B1 (SCL), IC3.12 (SCX), R4.1, R17.2, TP_SCL.TP, U1.P$M2 (P0.07)
SDA/1.4C: IC2.B2 (SDA), U3.8 (SDA)
SDA/2.4C: IC1.C1 (SDA), IC3.2 (SDX), R2.1, R18.2, TP_SDA.TP, U1.P$L1 (P0.06)
SWDCLK: J2.4, TP_SWDCLK.TP, U1.P$AA24 (SWDCLK)
SWDIO: J2.2, TP_SWDIO.TP, U1.P$AC24 (SWDIO)
SWO: TP_SWO.TP, U1.P$AD22 (P1.00)
VBAT/1.2A: C27.2, TP_VBAT.TP, U3.2 (CELL), U3.3 (VDD)
VBAT/2.5C: C37.1, IC1.C2 (BAT)
VBUS/1.5D: C42.1, C43.1, D3.5 (VBUS), J4.A4_B9 (VBUS), J4.A9_B4 (VBUS)
VBUS/2.6D: C21.1, C38.1, IC1.A2 (IN), U1.P$AD2 (VBUS)
VREG: C23.2, C24.1, C39.1, IC1.B2 (SYS), IC9.A1 (EN), IC9.A2 (VIN_1), IC9.A3 (VIN_2)

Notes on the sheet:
SWD
IMU
DEC1
DEC4_6
DEC3
LIPo Charger
DC/DC
E-Paper Drive Circuit
E-Paper Display Connector
Fuel Gauge
Buttons
Haptic Driver
USB C Connector & ESD Protection
MCU, Power, IMU, SWD
drawn by: Tudor Robu
E-Paper & Peripherals

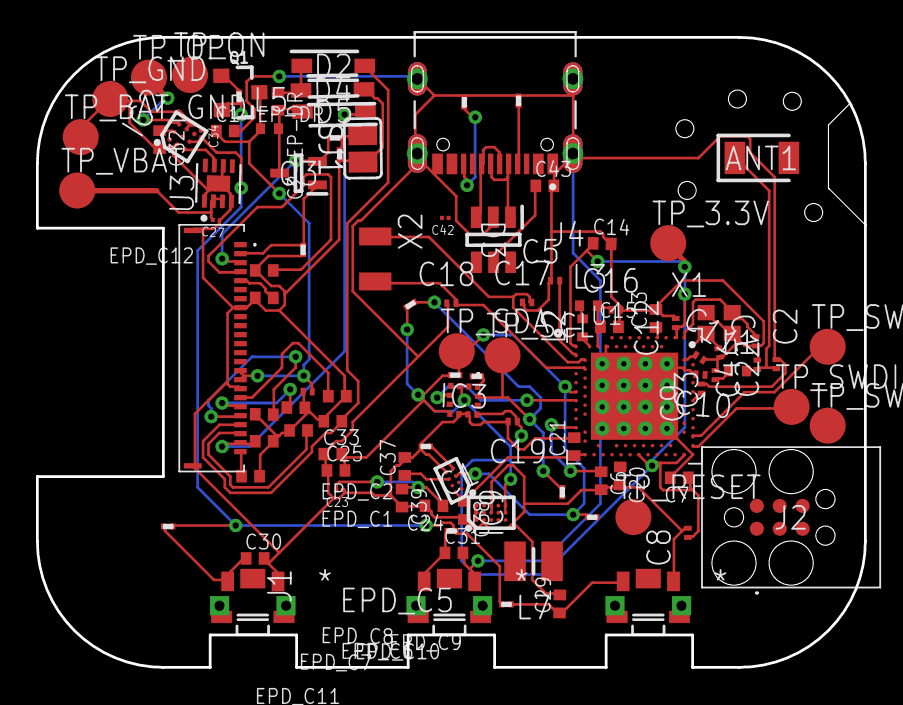
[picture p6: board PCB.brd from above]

Board: 2 copper layers, 46.0 x 35.0 mm, 103 parts (0 on the bottom side), 66 nets.

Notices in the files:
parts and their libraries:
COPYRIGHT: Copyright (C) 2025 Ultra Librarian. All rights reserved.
